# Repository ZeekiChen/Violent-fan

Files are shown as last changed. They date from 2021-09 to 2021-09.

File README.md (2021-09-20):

# Violent-fan
自制手持1s无刷风扇  
最大工作电流3A  
续航未知  
使用：  
* 1306，3100Kv无刷电机
* 3.5寸8叶穿越机桨叶
* 1节18650电池
* 无刷电调：开源无刷电调BLHeli
# DIY注意事项
DIY有风险，请电路上电之前反复确认是否存在引脚短路，虚焊等问题  
保险丝是不可省略的器件  
如果有条件，测试时最好使用有电流保护功能的直流电源来代替电池  
电池请选择正规渠道生产的18650电池，安全性有保障  
本人不为DIY本项目过程中意外造成的人员财产损失负责
# 制作流程
请仔细阅读工程文件夹下的`参考制作流程.pdf`  
相关问题交流讨论QQ群：930270812

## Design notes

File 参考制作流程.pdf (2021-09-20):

注意

DIY 有风险，请电路上电之前反复确认是否存在引脚短路，虚焊等问题 保险丝是不可省略的器件
如果有条件，测试时最好使用有电流保护功能的直流电源来代替电池 电池请选择正规渠道生产的 18650 电池，安全性有保障
本人不为 DIY 本项目过程中意外造成的人员财产损失负责

# 制作准备

## 使用”\HARDWAREPCB\violent fan.PcbDoc”文件打板，板子厚度选择 1mm 购买”\HARDWAREPCB\BOM.xlsx”表中的电子元器件和相关零件 使用“\3DModel3D\风扇外壳后盖.STL”和“\3DModel3D\风扇外壳主体.STL”文件打印外壳模型

# 第一步：焊接 PCB

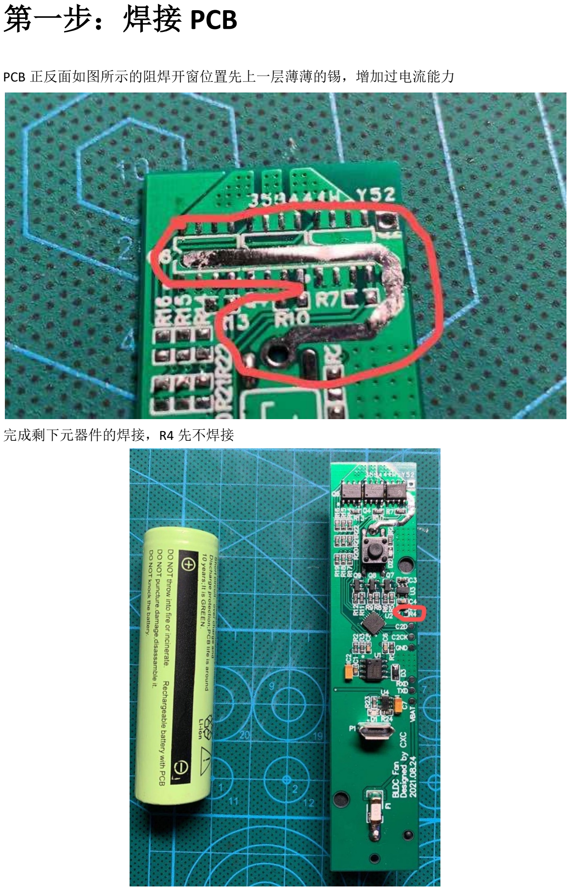
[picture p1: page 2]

PCB 正反面如图所示的阻焊开窗位置先上一层薄薄的锡，增加过电流能力

完成剩下元器件的焊接，R4 先不焊接

# 第二步:下载单片机程序

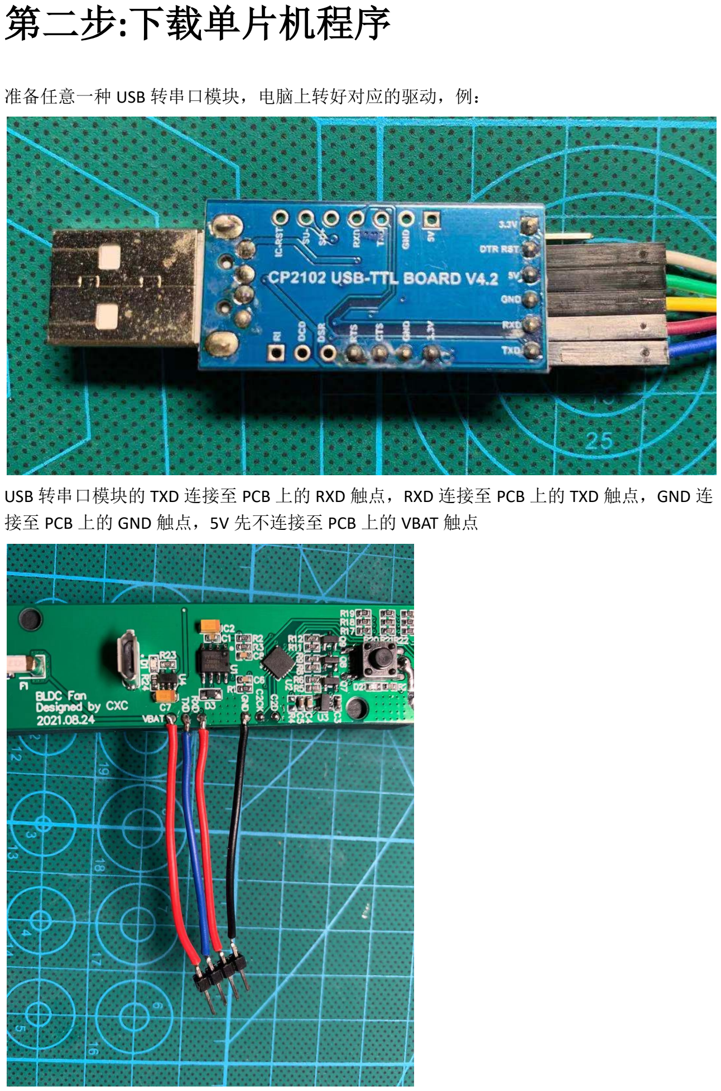
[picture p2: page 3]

准备任意一种 USB 转串口模块，电脑上转好对应的驱动，例：

## USB 转串口模块的 TXD 连接至 PCB 上的 RXD 触点，RXD 连接至 PCB 上的 TXD 触点，GND 连

接至 PCB 上的 GND 触点，5V 先不连接至 PCB 上的 VBAT 触点

## 准备 STC-ISP 下载器，下载链接 www.stcmcu.com，在网页右侧

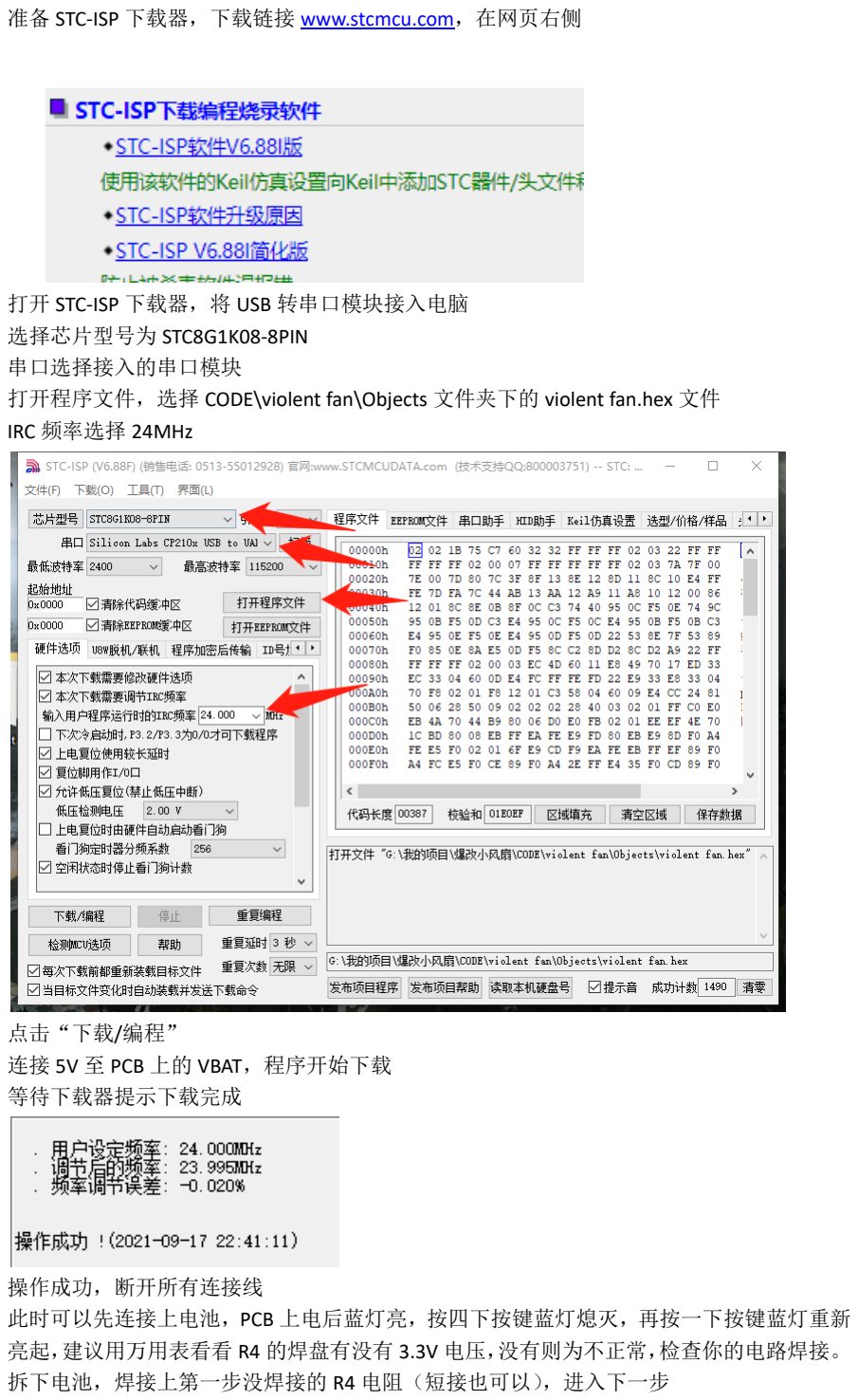
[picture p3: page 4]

打开 STC-ISP 下载器，将 USB 转串口模块接入电脑

## 选择芯片型号为 STC8G1K08-8PIN

串口选择接入的串口模块

## 打开程序文件，选择 CODE\violent fan\Objects 文件夹下的 violent fan.hex 文件 IRC 频率选择 24MHz

点击“下载/编程”
连接 5V 至 PCB 上的 VBAT，程序开始下载 等待下载器提示下载完成

操作成功，断开所有连接线
此时可以先连接上电池，PCB 上电后蓝灯亮，按四下按键蓝灯熄灭，再按一下按键蓝灯重新 亮起，建议用万用表看看 R4 的焊盘有没有 3.3V 电压，没有则为不正常，检查你的电路焊接。 拆下电池，焊接上第一步没焊接的 R4 电阻（短接也可以），进入下一步

# 第三步：下载 BLHeli 固件

下载 BLHeliSuite，链接：https://www.mediafire.com/folder/dx6kfaasyo24l/BLHeliSuite
BLHeli 固件的下载需要专门的下载器，省事的话可以直接上淘宝购买 如果手里有 Arduino 的朋友，链接里介绍使用 Arduino 制作成下载器的方法

## https://www.elvinplay.com/how-to-flash-esc-with-blheli-without-soldering/

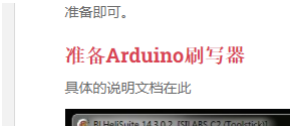
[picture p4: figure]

下载器准备完成
用购买的或者 arduino 制作的下载器，连接至 PCB 上这几个触点:

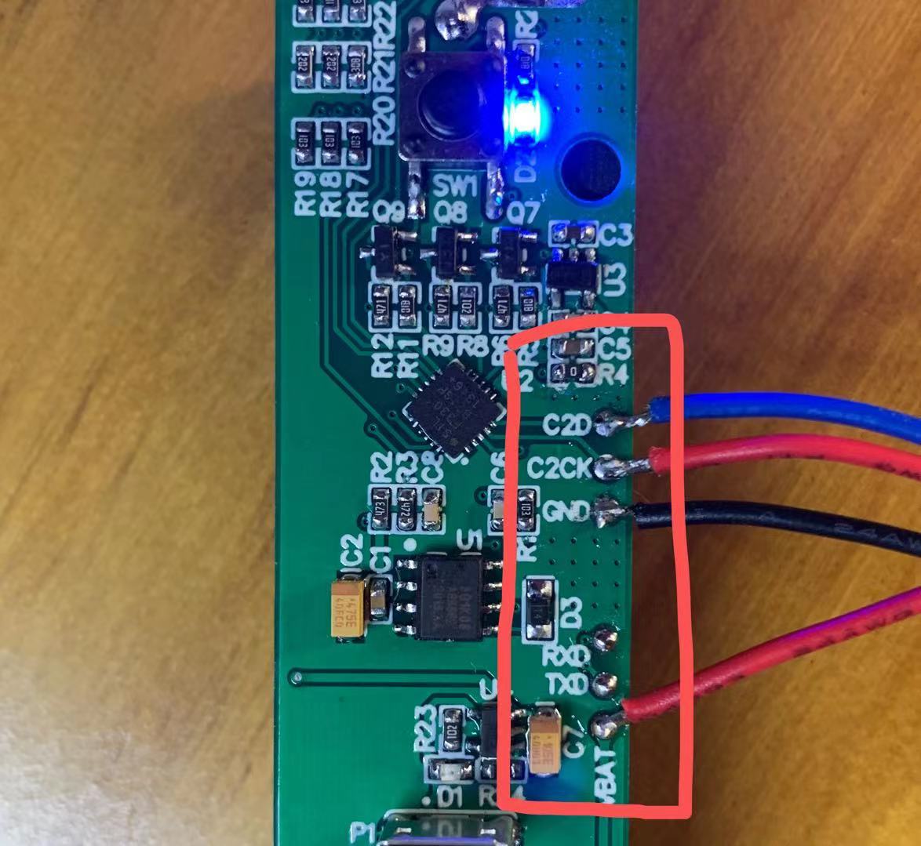
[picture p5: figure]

## 打开 BLHeliSuite，下载器接入电脑

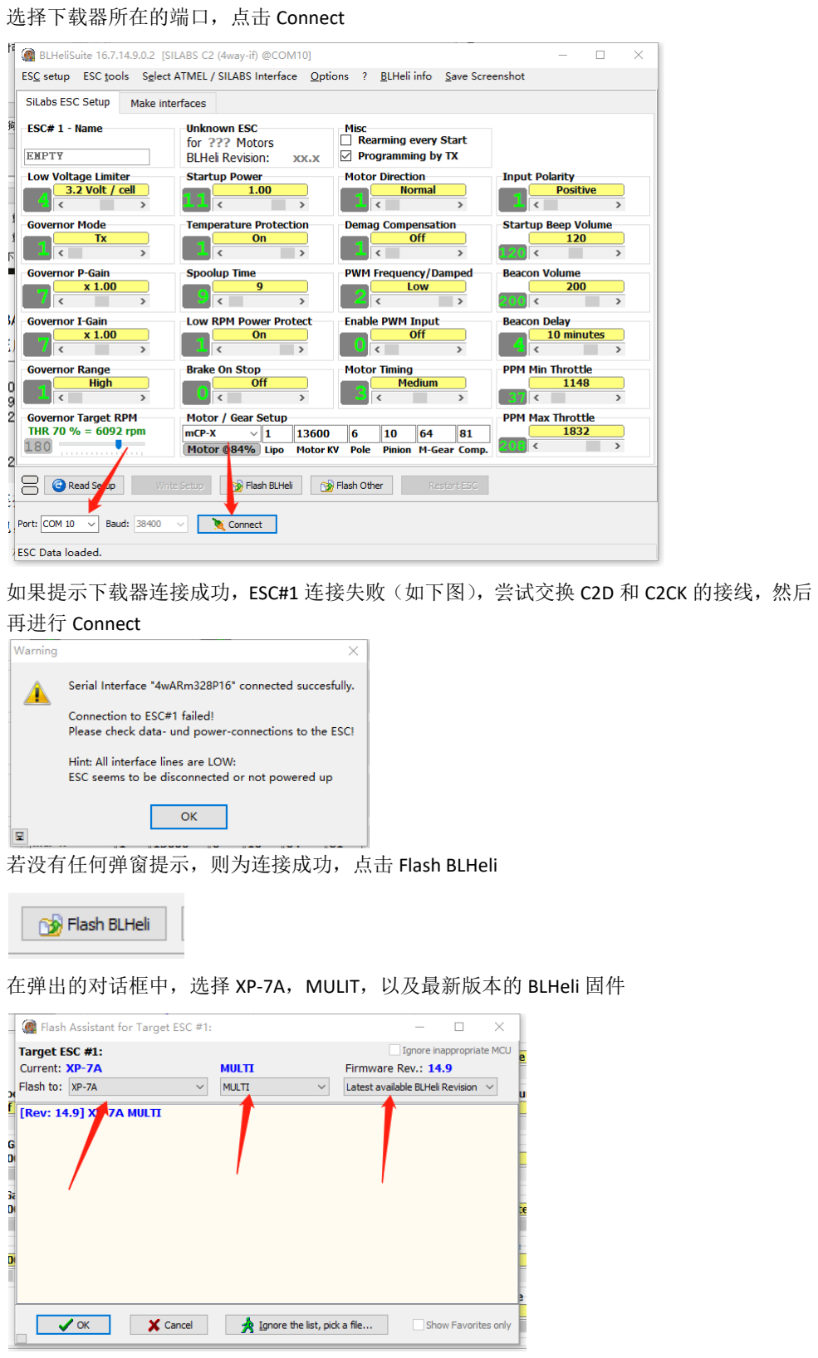
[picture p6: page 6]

选择下载器所在的端口，点击 Connect

如果提示下载器连接成功，ESC#1 连接失败（如下图），尝试交换 C2D 和 C2CK 的接线，然后

## 再进行 Connect

若没有任何弹窗提示，则为连接成功，点击 Flash BLHeli

在弹出的对话框中，选择 XP-7A，MULIT，以及最新版本的 BLHeli 固件

在弹出的对话框中，点击 YES 继续

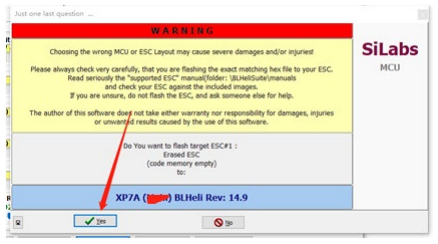
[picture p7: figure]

显示如下提示，即刷写成功

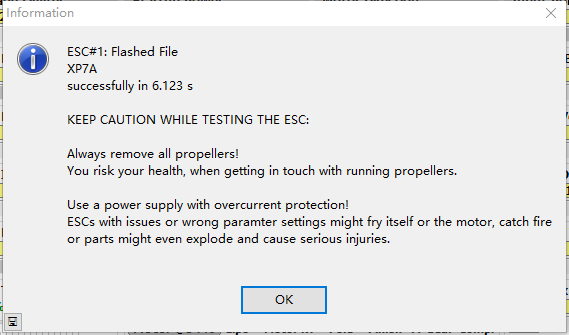
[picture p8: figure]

点击 OK 之后，在接下来弹出的对话框中，选择 NO

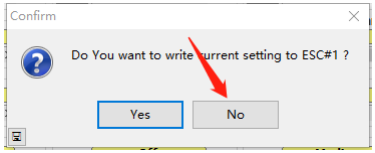
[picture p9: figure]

## 1． Startup Power 调整位最大的 1.5 2． Demag Compensation 调整为 off

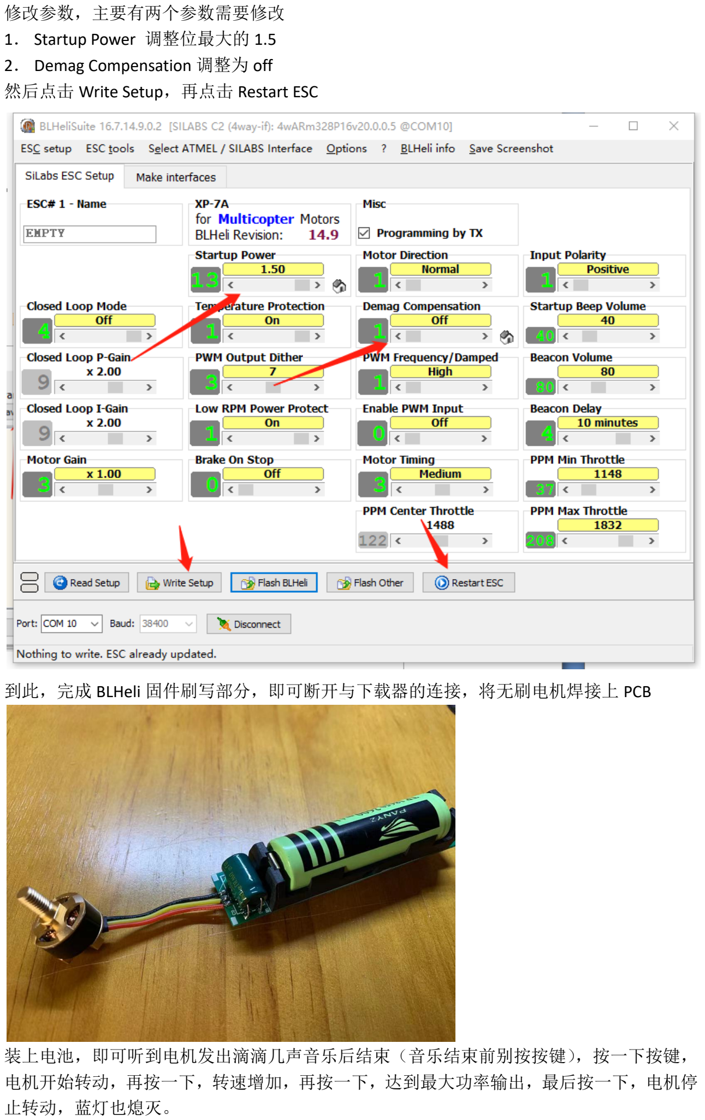
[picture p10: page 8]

修改参数，主要有两个参数需要修改

## 然后点击 Write Setup，再点击 Restart ESC

到此，完成 BLHeli 固件刷写部分，即可断开与下载器的连接，将无刷电机焊接上 PCB

装上电池，即可听到电机发出滴滴几声音乐后结束（音乐结束前别按按键），按一下按键， 电机开始转动，再按一下，转速增加，再按一下，达到最大功率输出，最后按一下，电机停 止转动，蓝灯也熄灭。

# 第四步：装配

准备：
1. 打印好的外壳

## 2. 1306 无刷电机一个 3. 18650 电池一个

4. 3.5 寸桨叶一个（一般是正反桨各两个共四个一起卖的）

## 5. M5 螺母一个 6. M2 螺母一个 7. M2 螺丝 5 个，丝杆长 5mm

8. 下载好单片机程序和 BLHeli 固件的，功能正常的 PCB 一个

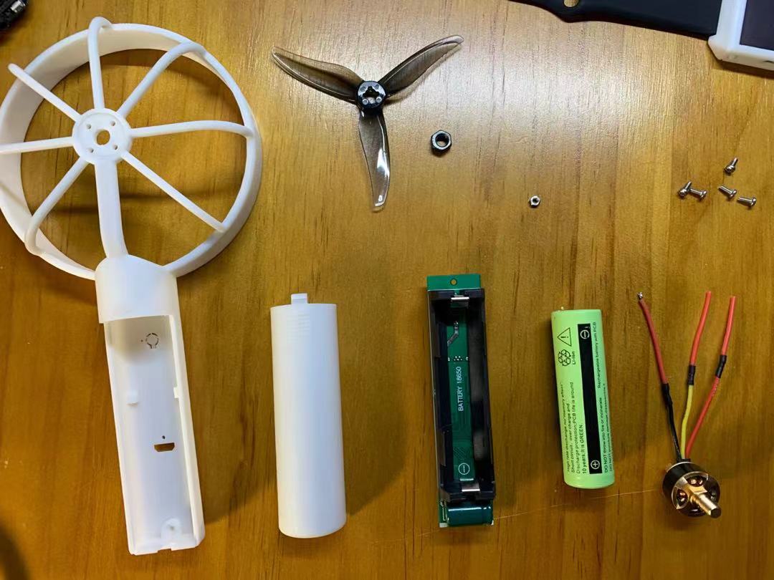
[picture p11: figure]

将 M2 螺母使用胶水固定在外壳预留的空位上，等待其固定

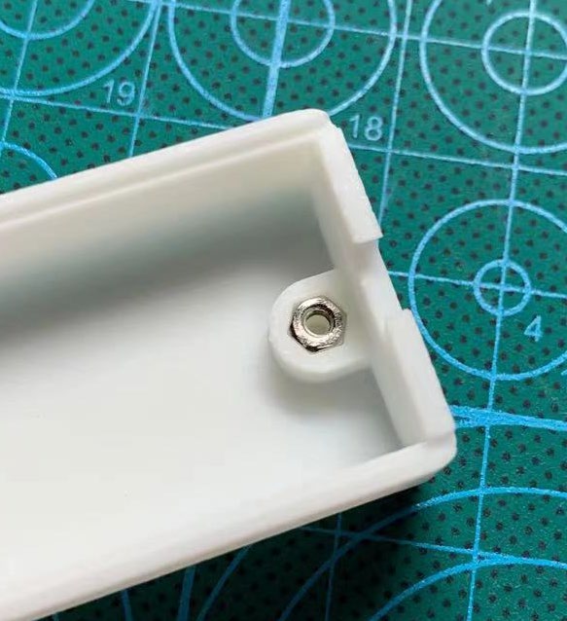
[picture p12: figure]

根据需要适当延长电机线，注意绝缘

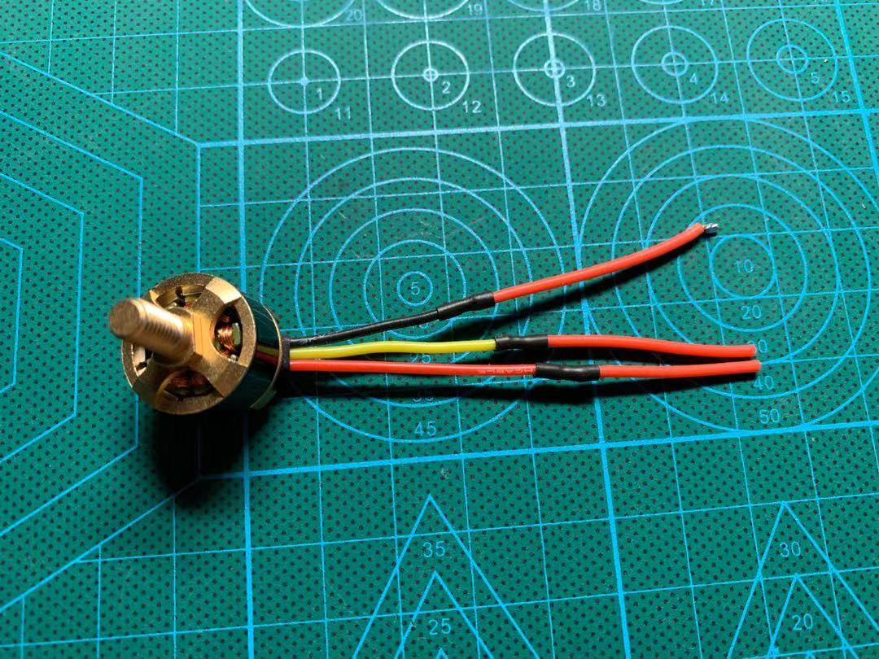
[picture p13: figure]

电机线穿过外壳预留的小孔，先与 PCB 上如图所示的三个焊盘焊接好

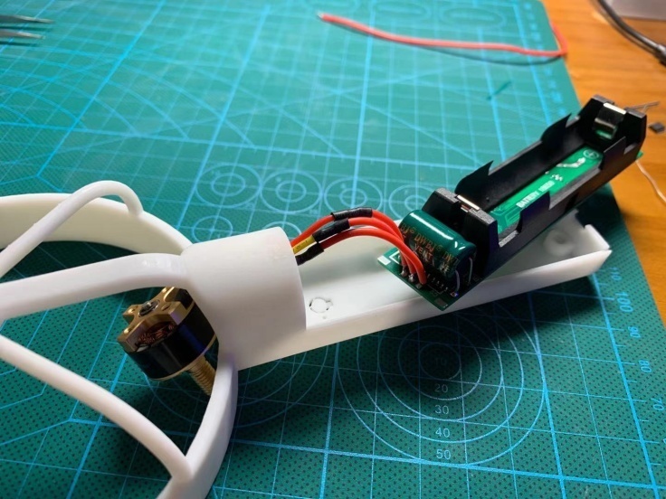
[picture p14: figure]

将 PCB 卡入如图所示的两个定位槽里

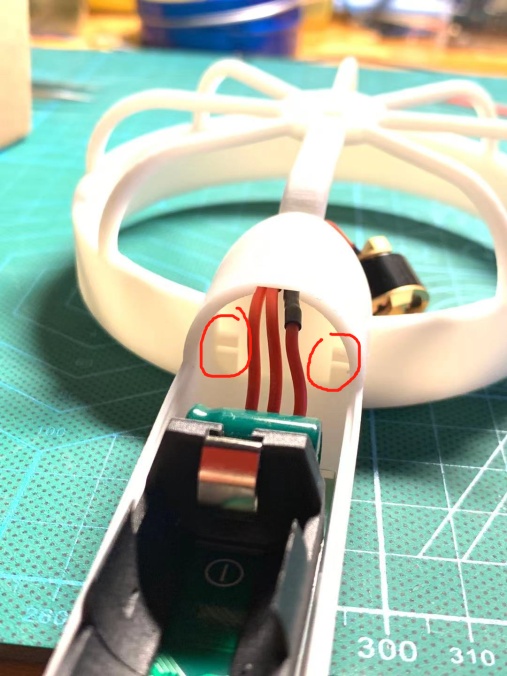
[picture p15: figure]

随后对准并用力，将 MICRO USB 接口扣进外壳上预留的孔中

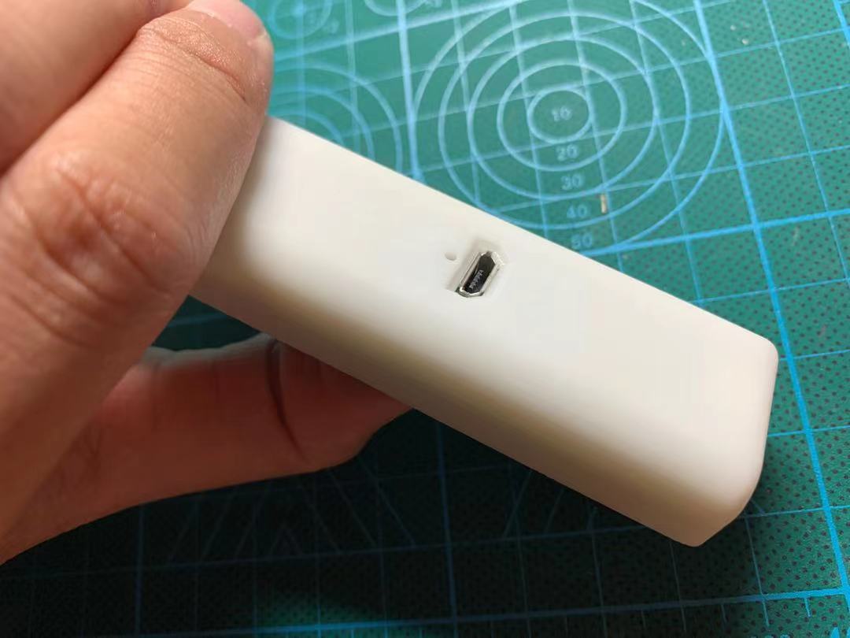
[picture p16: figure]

使用 M2 螺丝将 PCB 固定在外壳上

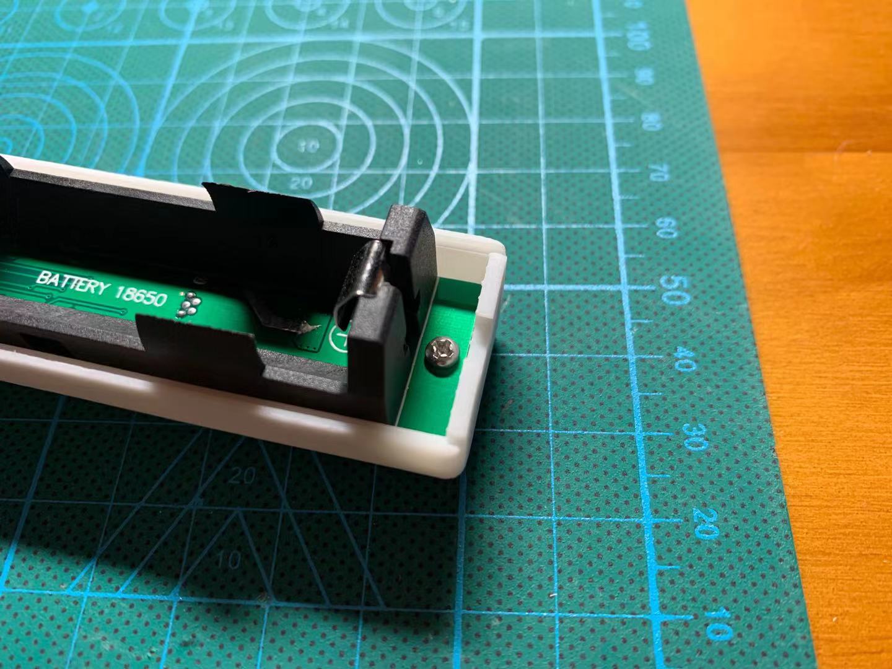
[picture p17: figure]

使用 M2 螺丝将电机固定在外壳上

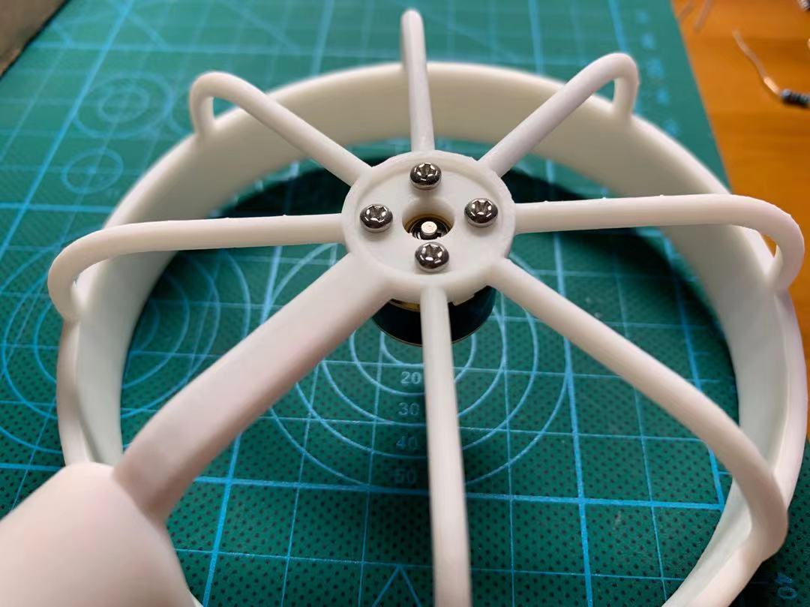
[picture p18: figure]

将电机线整理好在外壳预留的线槽里，避免被桨叶打到

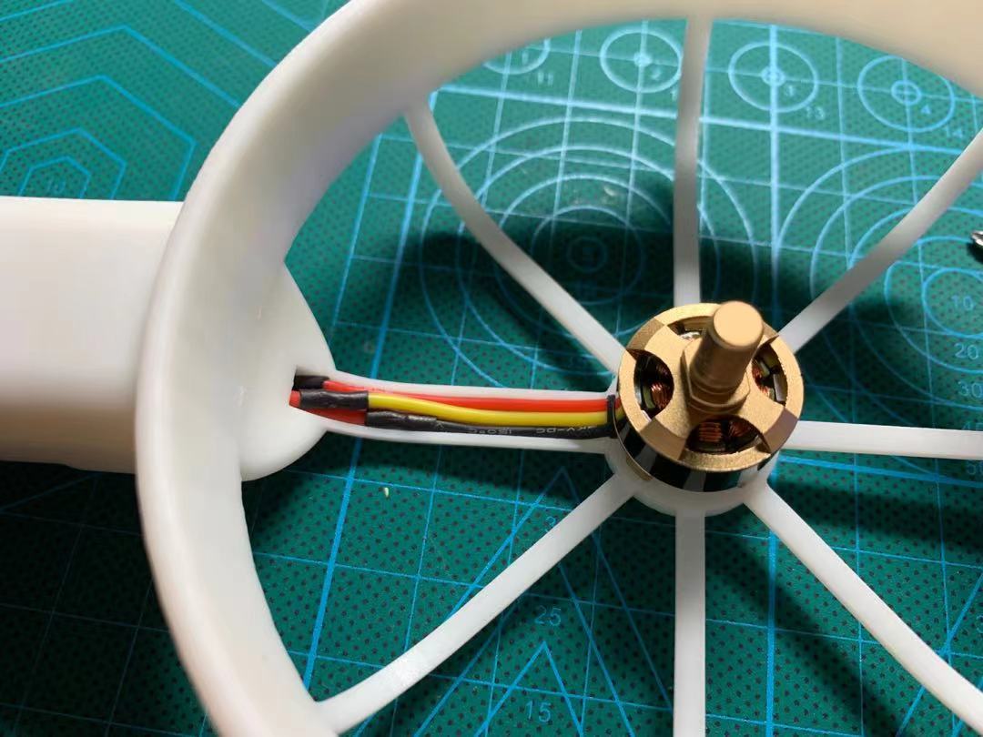
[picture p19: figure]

最后启动风扇根据电机的转向，来选择安装正桨还是反桨

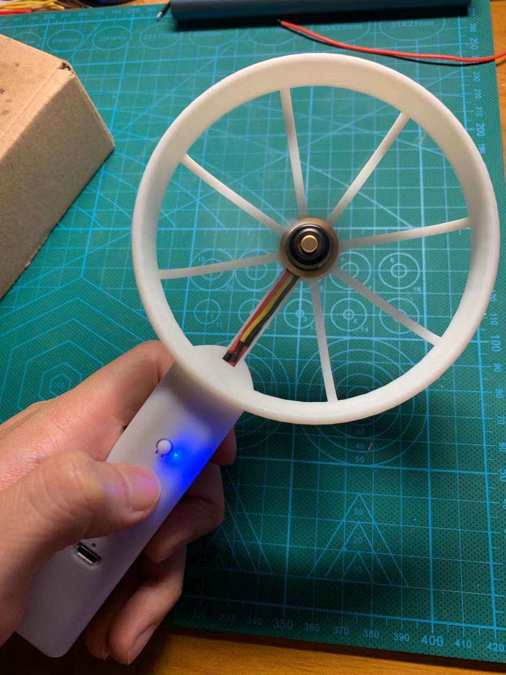
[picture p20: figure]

到此，整个风扇的装配完成

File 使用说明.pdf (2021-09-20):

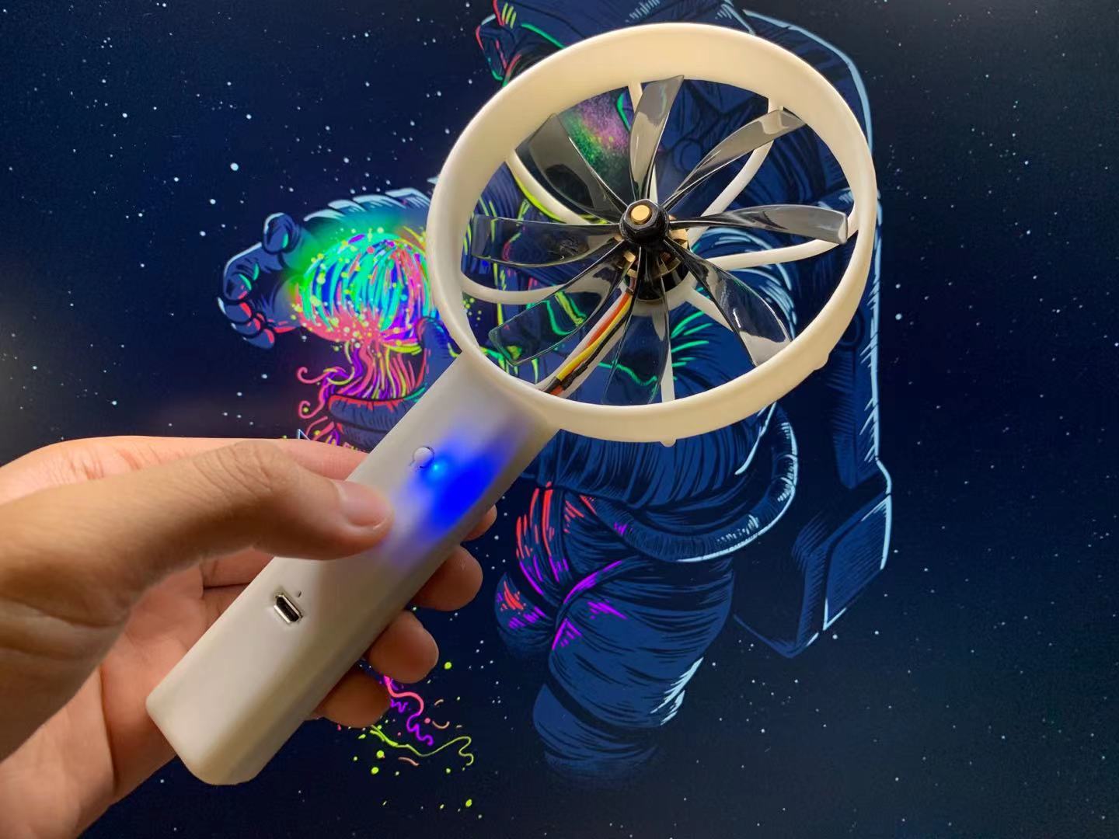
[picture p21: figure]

在关闭状态下，按一下按键，风扇开机，蓝色指示灯亮起，此时电机会发出滴滴 的音乐声，音乐声结束之前不要按按键
滴滴声结束后，按下按键可切换三个风速挡位
在最大风速挡位时，按下按键，风扇关机，蓝色指示灯熄灭 风扇手柄下方的 micro usb 接口为充电接口，切勿一边充电一边使用风扇 充电充满之前，红色指示灯会保持点亮
充电充满之后，红色指示灯熄灭
在任意开机状态下，没有操作按键超过 5 分钟，风扇自动关机

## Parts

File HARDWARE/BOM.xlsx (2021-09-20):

Comment | Description | Designator | 封装 | 数量 | 参考购买链接
0R | 贴片电阻 | R4 | R-0603 | 1 | https://youxin-electronic.taobao.com/category-1171156354.htm?search=y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
470R | 贴片电阻 | R6, R9, R12 | R-0603 | 3
1k | 贴片电阻 | R5, R8, R11, R24, R25 | R-0603 | 5
2k | 贴片电阻 | R20, R21, R22, R23 | R-0603 | 4
4.7k | 贴片电阻 | R3, R7, R10, R13 | R-0603 | 4
10k | 贴片电阻 | R1, R14, R15, R16, R17, R18, R19 | R-0603 | 7
47k | 贴片电阻 | R2 | R-0603 | 1
22nF | 无极性电容 | C4 | C-0603 | 1 | https://youxin-electronic.taobao.com/category-1145410923.htm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
0.1uF | 无极性电容 | C1, C6, C8 | C-0603 | 3
1uF | 无极性电容 | C3, C5 | C-0603 | 2
4.7uF | 有极性电容 | C7 | C-钽电容-3216 | 1 | https://item.taobao.com/item.htm?spm=a1z10.3-c-s.w4002-21223910208.58.6ce86a4brjWe1z&id=536844429229
10uF | 有极性电容 | C2 | C-钽电容-3216 | 1 | https://item.taobao.com/item.htm?spm=a1z10.3-c-s.w4002-21223910208.19.51e16a4bU2h60F&id=536882276924
470uF | 有极性电容 | C9 | CAP 5.0*10*16-H - GD | 1 | https://item.taobao.com/item.htm?spm=a1z09.2.0.0.5acc2e8dLRH7CL&id=564923141288&_u=fb2i1bf8cab
LED | 红光贴片LED | D1 | LED-0603 | 1 | https://item.taobao.com/item.htm?spm=a1z10.3-c-s.w4002-21223910208.10.1b2b6a4bbUWdWp&id=522554271548
LED | 蓝光贴片LED | D2 | LED-0603 | 1 | https://item.taobao.com/item.htm?spm=a1z10.3-c-s.w4002-21223910208.13.1fc26a4bRNCM9m&id=522573257623
1N4148 | 高速开关二极管 | D3 | SOD-323 | 1 | https://item.taobao.com/item.htm?spm=a1z10.3-c-s.w4002-21223910208.15.fc8e6a4bevpQCQ&id=528141270044
10A | 贴片保险丝 | F1 | FU 1808 | 1 | https://item.taobao.com/item.htm?spm=a1z09.2.0.0.5acc2e8dLRH7CL&id=560195140249&_u=fb2i1bf0969
NCE30P25S | P沟道-30V/-25A 贴片MOSFET | Q1, Q3, Q5 | SOP8 | 3 | https://item.taobao.com/item.htm?spm=a1z09.2.0.0.5acc2e8dLRH7CL&id=648700064612&_u=fb2i1bfe809
NCE2025S | N沟道20V/25A 贴片MOSFET | Q2, Q4, Q6 | SOP8 | 3 | https://item.taobao.com/item.htm?spm=a1z09.2.0.0.5acc2e8dLRH7CL&id=649175997191&_u=fb2i1bf1f9b
SS8050 | NPN型三极管 | Q7, Q8, Q9 | SOT-23 | 3 | https://item.taobao.com/item.htm?spm=a1z10.3-c-s.w4002-21223910208.9.71f36a4bJ5YFMK&id=522573790562
STC8G1K08 | 增强型51单片机 | U1 | SOP8 | 1 | https://item.taobao.com/item.htm?spm=a1z10.3-c-s.w4002-21223910208.9.36246a4bnk8qcK&id=637791845799
C8051F330 | silicon labs/8位51内核单片机 | U2 | QFN20 4x4 | 1 | https://item.taobao.com/item.htm?spm=a1z10.3-c-s.w4002-21223910208.9.799b6a4bCoV1Iq&id=522573798814
RT9193-33GB | LDO-3.3v | U3 | SOT23-5 | 1 | https://item.taobao.com/item.htm?spm=a1z10.3-c-s.w4002-21223910208.9.63116a4bknkkdl&id=522574021262
XT4054 | 锂电池充电ic | U4 | SOT23-5 | 1 | https://item.taobao.com/item.htm?spm=a1z10.3-c-s.w4002-21223910208.12.60e66a4bwmGNgY&id=588004132796
Button | 轻触开关 | SW1 | TSW SMD-6*6*4.3 | 1 | https://item.taobao.com/item.htm?spm=a1z10.3-c-s.w4002-21223910208.18.35de6a4btW2CgE&id=556973844714
BATTERY HOLDER | 电池座、电池位 | B1 | 18650电池座-直插式 | 1 | https://item.taobao.com/item.htm?spm=a1z09.2.0.0.af142e8d1Xe6rY&id=589677534830&_u=fb2i1bf747e
MICRO USB | MICRO USB接口 | P1 | MICRO USB-立式卷边 | 1 | https://item.taobao.com/item.htm?spm=a1z09.2.0.0.af142e8d1Xe6rY&id=538149609344&_u=fb2i1bf6995
电池 |  |  | 18650 | 1
螺丝 |  |  | M2，丝杆长5mm | 5 | https://item.taobao.com/item.htm?spm=a1z10.3-c-s.w4002-21223910208.49.2bc86a4bEtKQOw&id=555340649969
螺母 |  |  | M2 | 1 | https://item.taobao.com/item.htm?spm=a1z10.3-c-s.w4002-21223910208.21.7e056a4bLcZdOg&id=555374805934
螺母 |  |  | M5 | 1 | https://item.taobao.com/item.htm?spm=a1z10.3-c.w4002-23908786233.12.66b48f8fYwP7Di&id=571571453536
无人机桨叶 |  |  | 3.5寸8叶FPV螺旋桨 | 4 | https://item.taobao.com/item.htm?id=652861902557&ns=1&abbucket=4 (https://item.taobao.com/item.htm?spm=a230r.1.14.16.4e441d97xD1Qq3&id=652861902557&ns=1&abbucket=4)
无刷电机 |  |  | 1306，3100Kv，CW正牙 | 1 | https://item.taobao.com/item.htm?spm=a1z09.2.0.0.38172e8dp7Balv&id=632170518587&_u=kb2i1bf7ddf

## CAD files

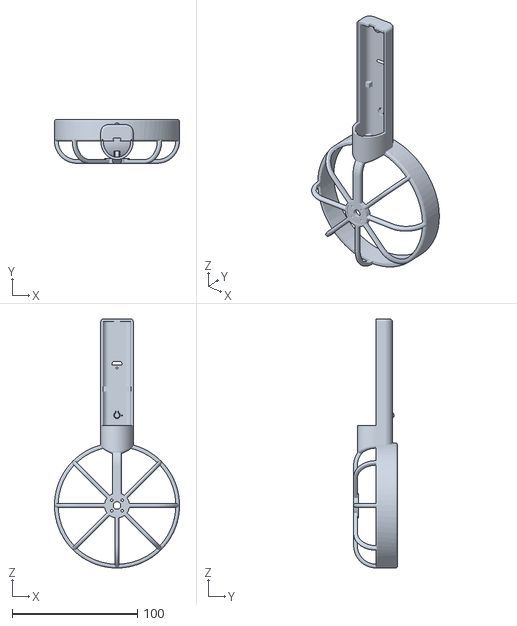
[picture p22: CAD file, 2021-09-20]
3DModel/风扇外壳主体.STL
100.0 x 35.0 x 199.0

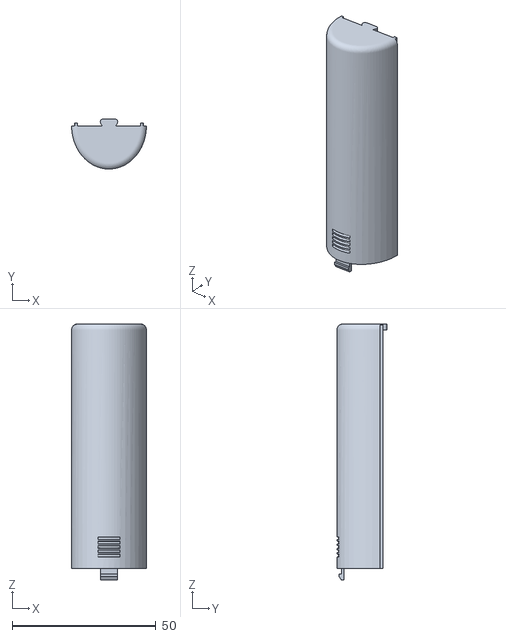
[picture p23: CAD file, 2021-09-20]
3DModel/风扇外壳后盖.STL
26.0 x 17.4 x 88.9

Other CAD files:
CODE/violent fan-20210920/Objects/main.obj

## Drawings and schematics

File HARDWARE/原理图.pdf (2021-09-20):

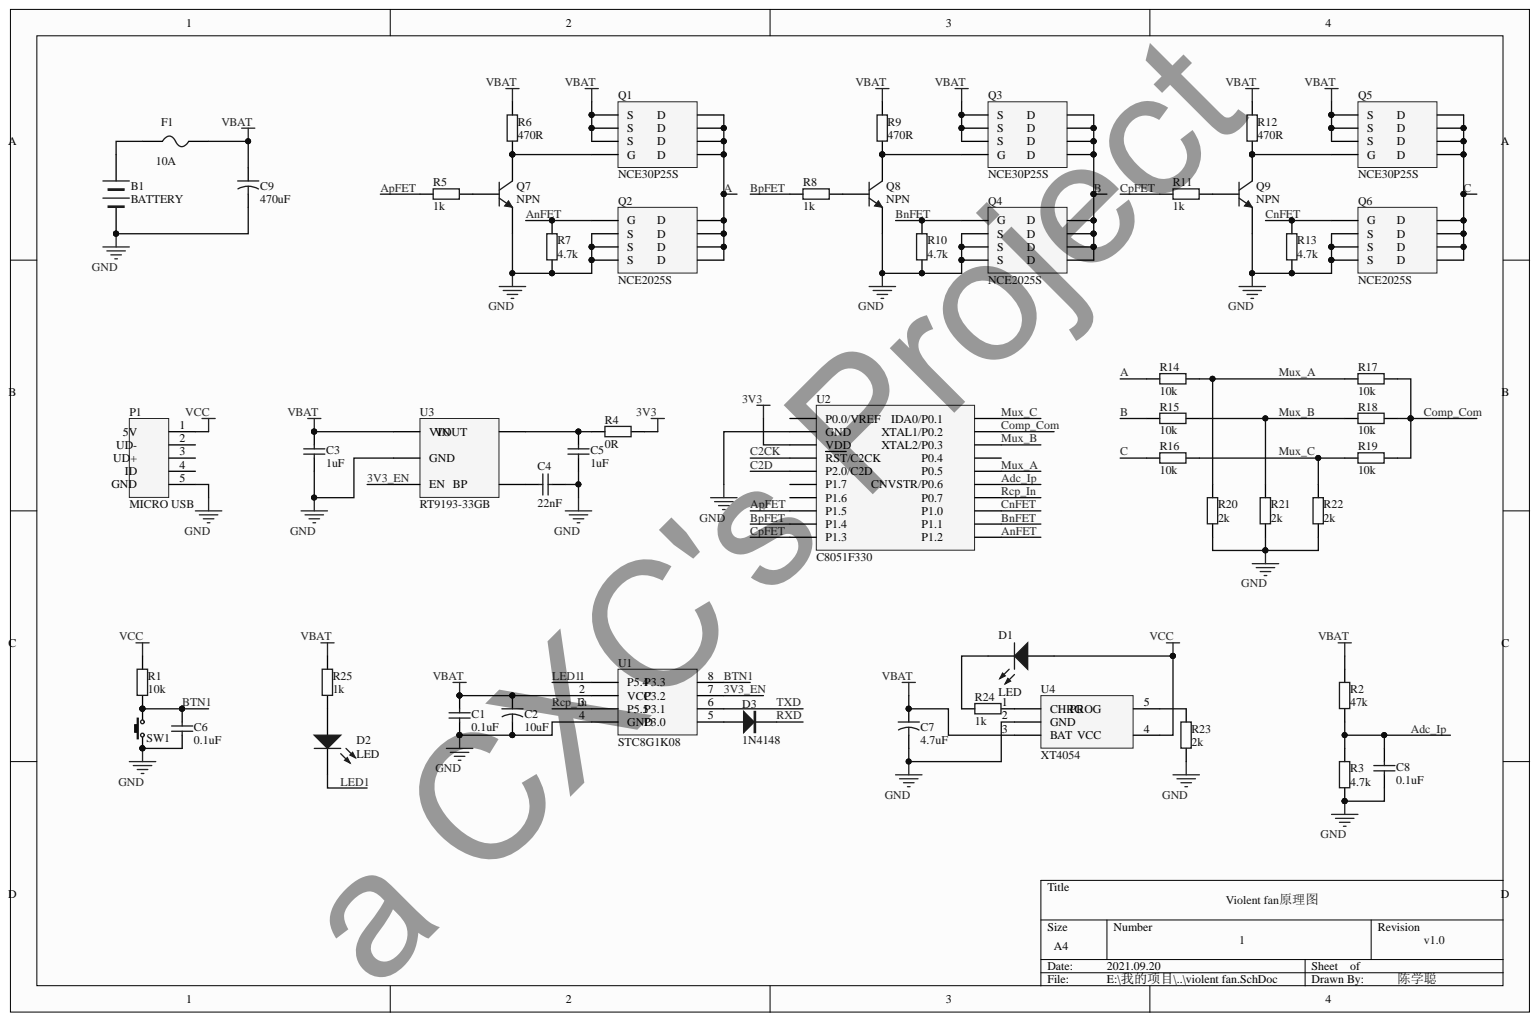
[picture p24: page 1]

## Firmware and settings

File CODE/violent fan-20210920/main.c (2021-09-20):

#include "STC8Gxx.h"
#include "intrins.h"

#define	EN3V3		P32
#define	KEY1		P33
#define	LED1		P54
#define PWM_OUT	P55
#define	PWM_T		40000

unsigned int T_h = 2000;
unsigned int T_l = 38000;
unsigned char mode = 0;
unsigned int inactive_cnt = 0;

void setPulsewidth(float pw)
{
	T_h = (pw - 1.0) * 2000 + 2000;
	T_l = PWM_T - T_h;
	T_h = 65536 - T_h;
	T_l = 65536 - T_l;
}

void Timer0Init(void)		//20毫秒@24.000MHz
{
	AUXR &= 0x7F;		//定时器时钟12T模式
	TMOD &= 0xF0;		//设置定时器模式
	TL0 = T_l;
	TH0 = T_l >> 8;
	TF0 = 0;				//清除TF0标志
	TR0 = 1;				//定时器0开始计时
	ET0 = 1;        //使能定时器中断
}
void TM0_Isr() interrupt 1
{	
	static unsigned char k = 0;
	if(k == 0)
	{
		k = 1;
		TL0 = T_h;
		TH0 = T_h >> 8;
		PWM_OUT = 0;
	}
	else
	{
		k = 0;
		TL0 = T_l;
		TH0 = T_l >> 8;
		PWM_OUT = 1;
	}
}
void Timer1Init(void)		//10毫秒@24.000MHz
{
	AUXR &= 0xBF;		//定时器时钟12T模式
	TMOD &= 0x0F;		//设置定时器模式
	TL1 = 0xE0;		//设置定时初始值
	TH1 = 0xB1;		//设置定时初始值
	TF1 = 0;		//清除TF1标志
	TR1 = 1;		//定时器1开始计时
	ET1 = 1;
}
void TM1_Isr() interrupt 3
{
	if(inactive_cnt++ == 30000)
	{
		KEY1 = 0;
		mode = 3;
	}
}
void INT4_Isr() interrupt 16
{
	IAP_CONTR = 0x60;
}
void INT1_Isr() interrupt 2
{
}
void Delay100ms()		//@24.000MHz
{
	unsigned char i, j, k;

	_nop_();
	_nop_();
	i = 10;
	j = 31;
	k = 147;
	do
	{
		do
		{
			while (--k);
		} while (--j);
	} while (--i);
}
void main()
{
	P3M0 = 0x00;
	P3M1 = 0x00;
	P5M0 = 0x10;
	P5M1 = 0x00;
	EN3V3 = 1;
	KEY1 = 1;
	LED1 = 0;
	PWM_OUT = 0;
	IT1 = 1;                                    //INT1下降沿中断
  EX1 = 1;                                    //使能INT1中断
	INTCLKO = 0x40;                             //使能INT4中断
	Timer0Init();
	Timer1Init();
	setPulsewidth(1.0);
	mode = 0;
  EA = 1;
	while(1)
	{
		Delay100ms();
		if(KEY1 == 0)
		{
			mode++;
			inactive_cnt = 0;
			if(mode == 1)
				setPulsewidth(1.3);
			else if(mode == 2)
				setPulsewidth(1.6);
			else if(mode == 3)
				setPulsewidth(1.9);
			else
			{
				setPulsewidth(1.0);
				EN3V3 = 0;
				LED1 = 1;
				KEY1 = 1;
				PCON = 0x02;
				_nop_();
				IAP_CONTR = 0x60;
			}
			while(KEY1 == 0);
		}
		
	}
}

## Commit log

2021-09-20 Add files via upload
    风扇外壳3D打印文件
    [风扇外壳主体.STL, 风扇外壳后盖.STL]
2021-09-20 Add files via upload
    电路原理图，PCB文件以及BOM表
    [BOM.xlsx]
